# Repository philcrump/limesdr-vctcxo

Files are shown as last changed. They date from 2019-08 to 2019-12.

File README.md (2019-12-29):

# limesdr-vctcxo

This PCB provides an external, thermally separate, TCXO Frequency Reference to the LimeSDR-mini board.

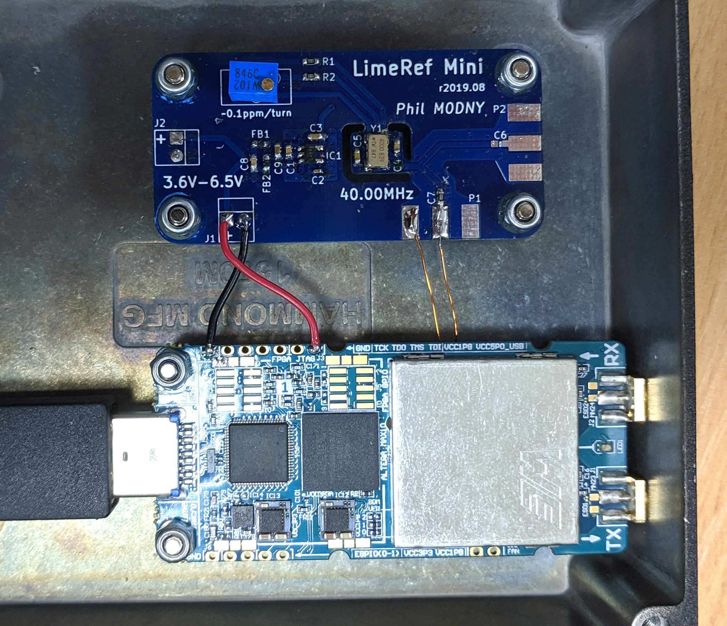
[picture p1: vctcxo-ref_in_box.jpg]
Photo in box with LimeSDR mini


I built this as even though the onboard TCXO is well-specced, being next to the high-power FPGA & RF components was causing noticeable thermal drift, especially in amplitude-modulated (eg. SSB) outdoor use.

This board uses a 40MHz TCXO to be a plug-in replacement with no reconfiguration. A 12-turn potentiometer allows easy manual calibration.

[Schematic PDF file](https://github.com/philcrump/limesdr-vctcxo/raw/master/vctcxo-ref.pdf)

## PCB Images

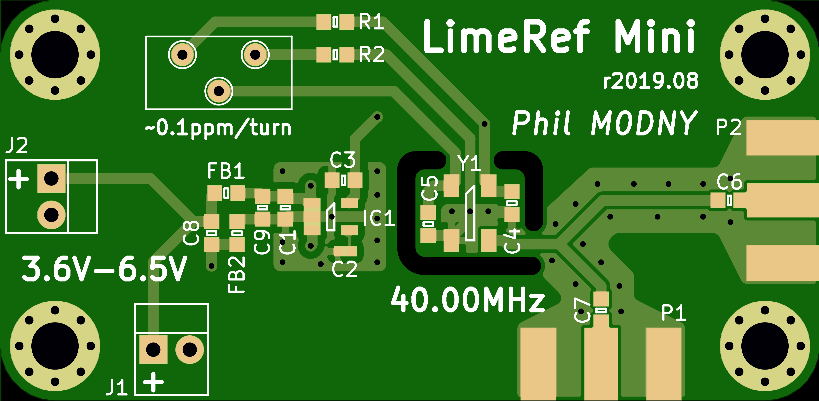
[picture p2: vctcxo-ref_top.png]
PCB Top


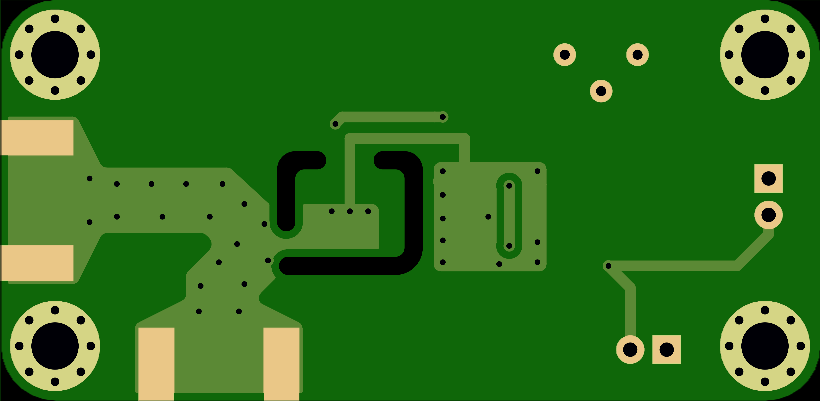
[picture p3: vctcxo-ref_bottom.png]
PCB Bottom


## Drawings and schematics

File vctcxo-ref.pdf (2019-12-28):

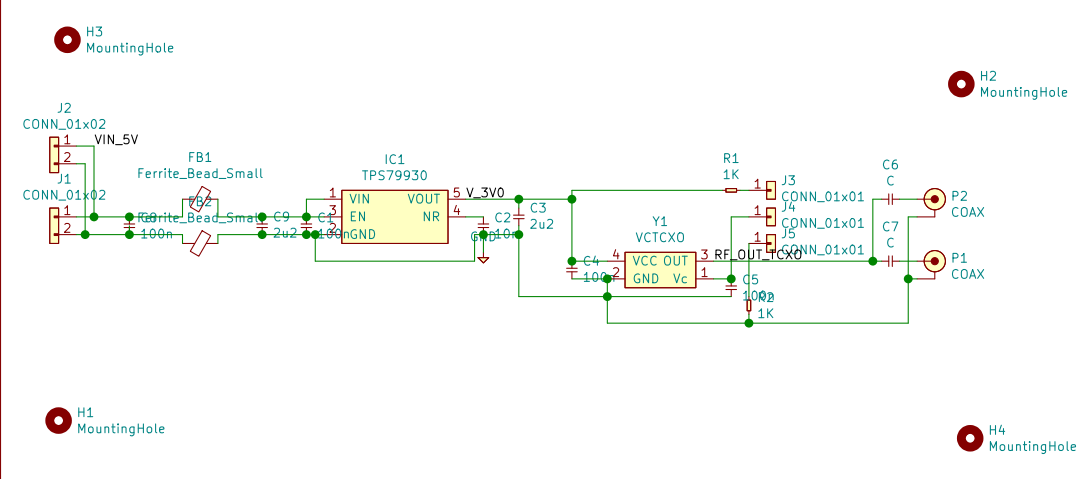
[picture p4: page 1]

Id: 1/1 Title: File: vctcxo-ref.sch Sheet: /

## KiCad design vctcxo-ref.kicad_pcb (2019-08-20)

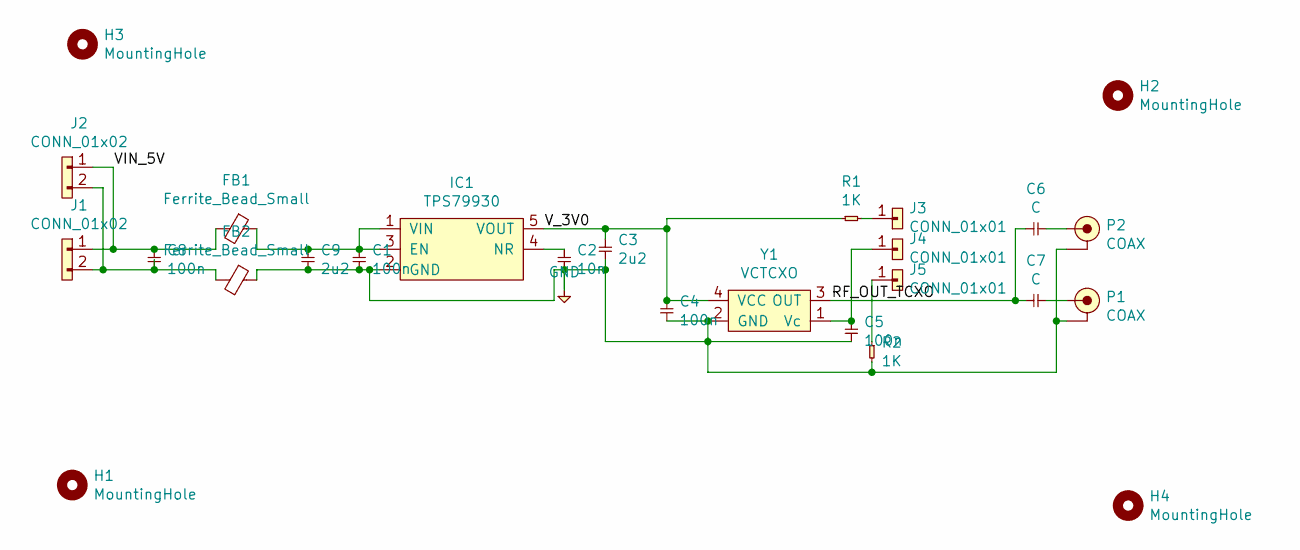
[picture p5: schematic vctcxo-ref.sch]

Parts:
C1, C4, C5, C8: 100n; 0603
C2: 10n; 0402
C3, C9: 2u2; 0603
C6, C7: C; 0603
FB1, FB2: Ferrite_Bead_Small; 0603
H1, H2, H3, H4: MountingHole; M3_MOUNT
IC1: TPS79930; SOT-23-5; Farnell 1135402
J1, J2: CONN_01x02; MOLEX-KK-254P-02
J3, J4, J5: CONN_01x01; TestPoint_THTPad_D1.5mm_Drill0.7mm
P1, P2: COAX; SMA-EDGE; Farnell 1608592
R1, R2: 1K; 0603
Y1: VCTCXO; XO-50x32; Farnell 2467929

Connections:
/RF_OUT_TCXO: C6.1, C7.1, Y1.3 (OUT)
/VIN_5V: C8.1, FB1.2, J1.1, J2.1
/V_3V0: C3.2, C4.2, IC1.5 (VOUT), R1.1, Y1.4 (VCC)
GND: C1.2, C2.2, C3.1, C4.1, C5.2, C9.1, FB2.1, IC1.2 (GND), P1.2 (GND), P2.2 (GND), R2.2, Y1.2 (GND)
unnamed: C1.1, C9.2, FB1.1, IC1.1 (VIN), IC1.3 (EN)
unnamed: C2.1, IC1.4 (NR)
unnamed: C5.1, J4.1, Y1.1 (Vc)
unnamed: C6.2, P2.1 (RF)
unnamed: C7.2, P1.1 (RF)
unnamed: C8.2, FB2.2, J1.2, J2.2
unnamed: J3.1, R1.2
unnamed: J5.1, R2.1

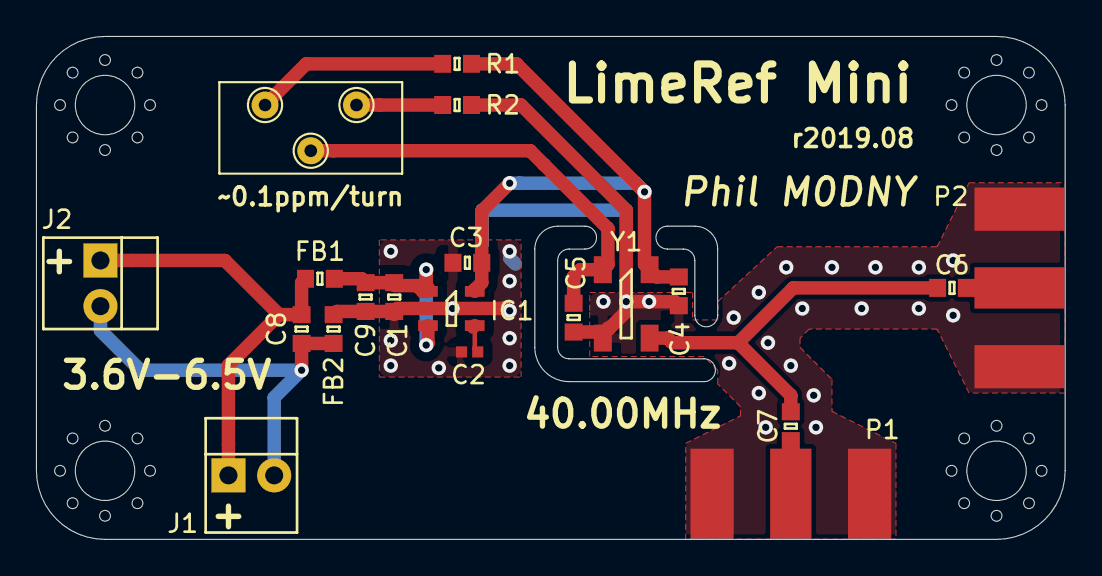
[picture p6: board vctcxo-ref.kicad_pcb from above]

Board: 2 copper layers, 57.2 x 27.9 mm, 26 parts (0 on the bottom side), 12 nets.

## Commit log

2019-08-05 lib/agg-kicad/: Fix submodule upstream (point to philcrump/ repo).
2019-08-19 Initial plot run.
    [vctcxo-ref-B_Cu.gbl, vctcxo-ref-B_Mask.gbs, vctcxo-ref-B_Paste.gbp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]
2019-08-20 Sent to fab.
    [vctcxo-ref-B_Cu.gbl, vctcxo-ref-B_Mask.gbs, vctcxo-ref-B_Paste.gbp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]
2019-12-28 Commit the BOM.
2019-12-28 Add schematic and pcb renders.
